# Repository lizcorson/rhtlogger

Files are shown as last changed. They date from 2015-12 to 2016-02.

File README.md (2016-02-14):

# rhtlogger
A temperature/relative humidity Arduino data logger. A sensor detects the current temperature and relative humidity. An LCD display updates every 3 seconds, and the values are logged to file every 30 seconds.

## Status

I soldered everything on to the proto shield, but I couldn't get the system to work reliably after that. I decided to completely redo everything using a Pro Mini because the stacking shields were annoying me. All of the new parts are still compatible with the same code.

## Parts Used

- Pro Mini Clone (5V) http://www.ebay.com/itm/231348215568 -- I especially like this new model because the A4/A5 I2C pins are in a much more convenient location
- Micro SD Card SPI module http://www.ebay.com/itm/Micro-SD-and-Memory-Card-Breakout-Shield-Module-via-SPI-For-Arduino-Regulated-/131426645939 - one that says Catalex on the back and has a voltage regulator
- DS3231 RTC http://www.ebay.com/itm/191782504379
- Clone of Sparkfun RHT Board HTU21D http://www.ebay.com/itm/310951642577?_trksid=p2057872.m2749.l2649&ssPageName=STRK%3AMEBIDX%3AIT (original: https://www.sparkfun.com/products/12064)
- 5V to 3.3V stepdown module http://www.ebay.com/itm/111896908030 (for the sensor, which is 3.3V)
- Frentaly i2c LCD http://www.ebay.com/itm/IIC-I2C-TWI-1602-Serial-Blue-Backlight-LCD-Display-For-Arduino-/221935534466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
- Momentary button https://www.sparkfun.com/products/11993
- 10k Ω resistor

Removed:
- SainSmart Uno http://smile.amazon.com/dp/B00E5WJSHK
- Arrela Data Logger Shield http://smile.amazon.com/dp/B00KHYHKT8 (I see this is no longer available - http://smile.amazon.com/dp/B00M1M8N90/ is probably a comparable replacement)
- tiny breadboard and/or protoshield with tiny breadboard http://www.ebay.com/itm/221739124245
- DHT22 sensor https://www.sparkfun.com/products/10167

## Libraries Used

- New LiquidCrystal library https://bitbucket.org/fmalpartida/new-liquidcrystal/downloads
- RTClib https://github.com/adafruit/RTClib
- HTU21D https://github.com/sparkfun/HTU21D_Breakout/tree/V_H1.2_L1.1.0/Libraries/Arduino

## Sample Data

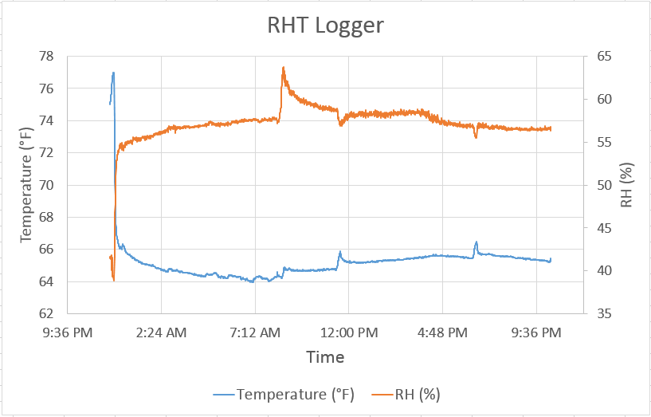
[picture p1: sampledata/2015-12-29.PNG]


## Photos

New breadboard prototype with the Pro Mini.

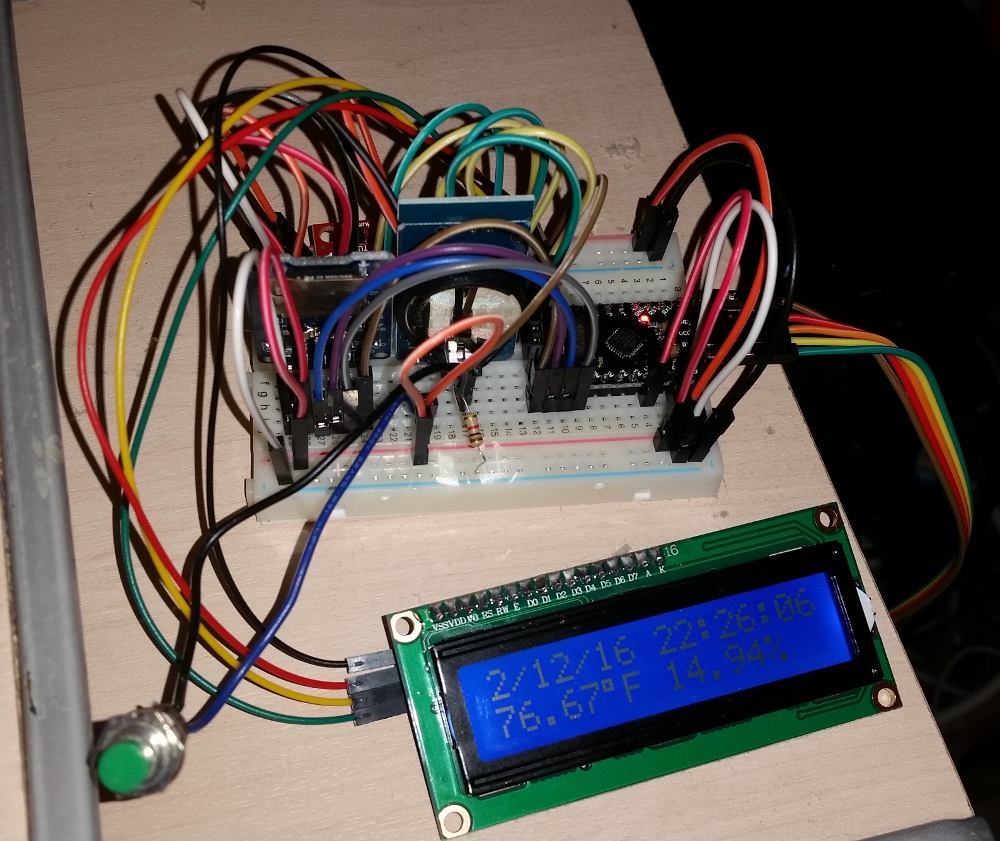
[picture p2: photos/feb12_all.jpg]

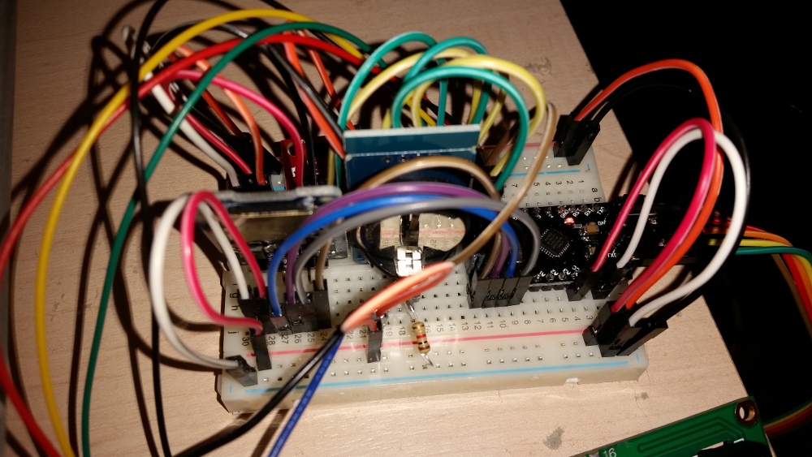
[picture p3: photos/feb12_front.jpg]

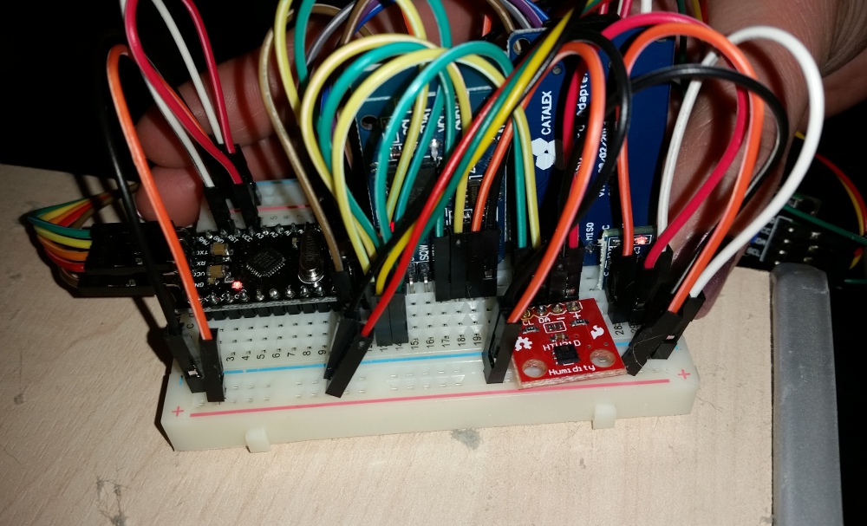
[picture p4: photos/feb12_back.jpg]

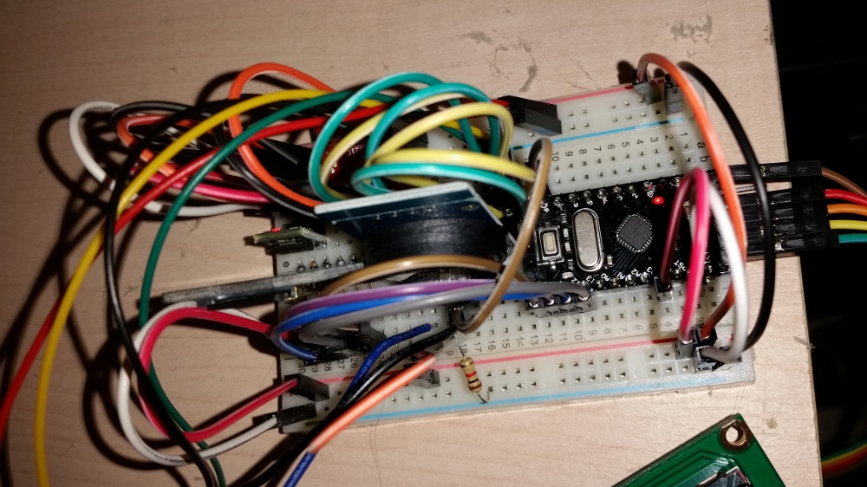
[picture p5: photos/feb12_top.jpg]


Proto-shield setup, which failed. 

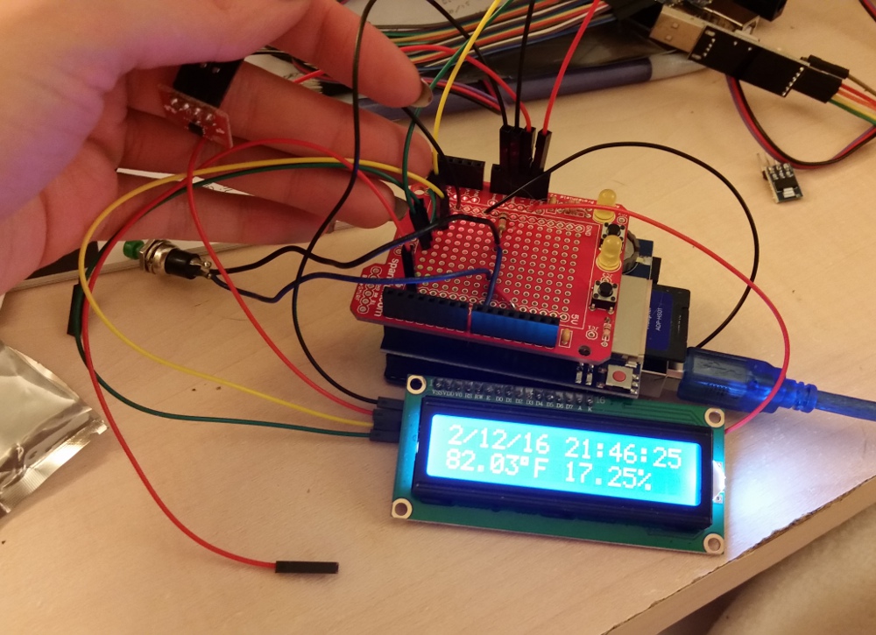
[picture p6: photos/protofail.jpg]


Original prototype with both DHT22 and HTU21D.

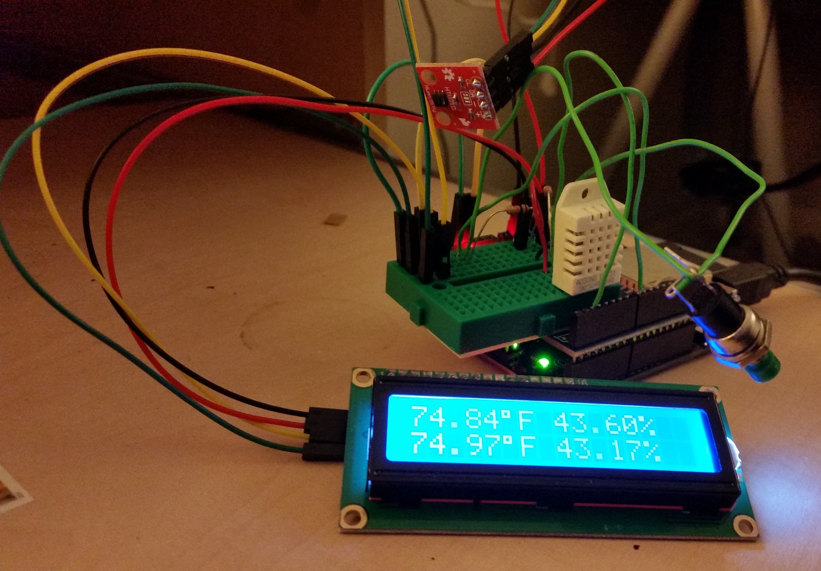
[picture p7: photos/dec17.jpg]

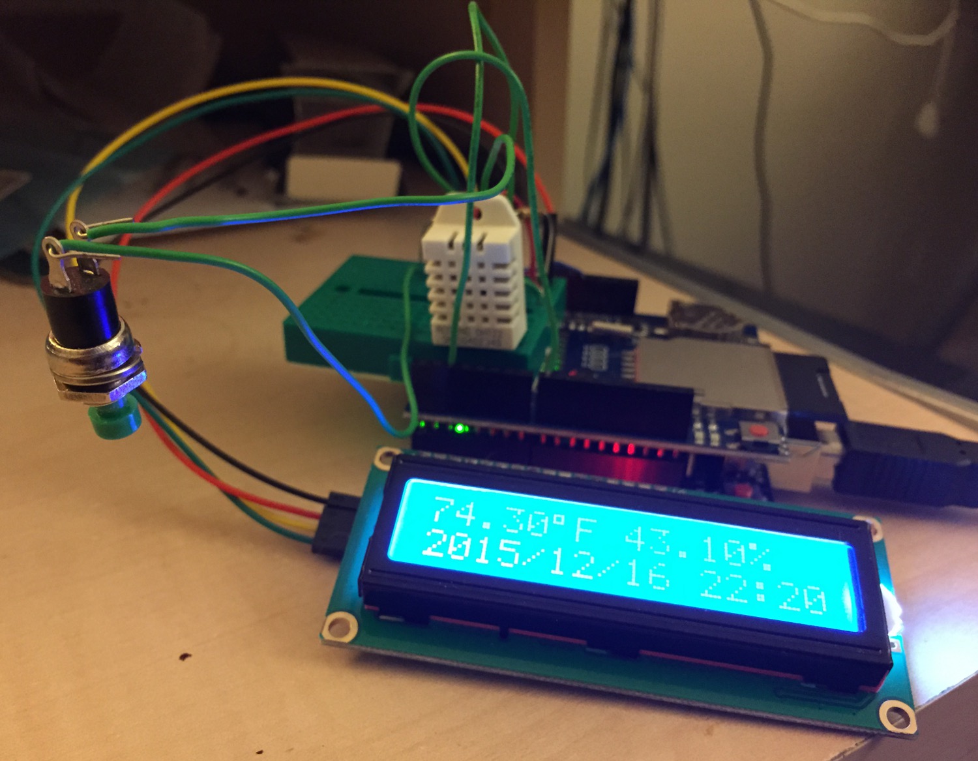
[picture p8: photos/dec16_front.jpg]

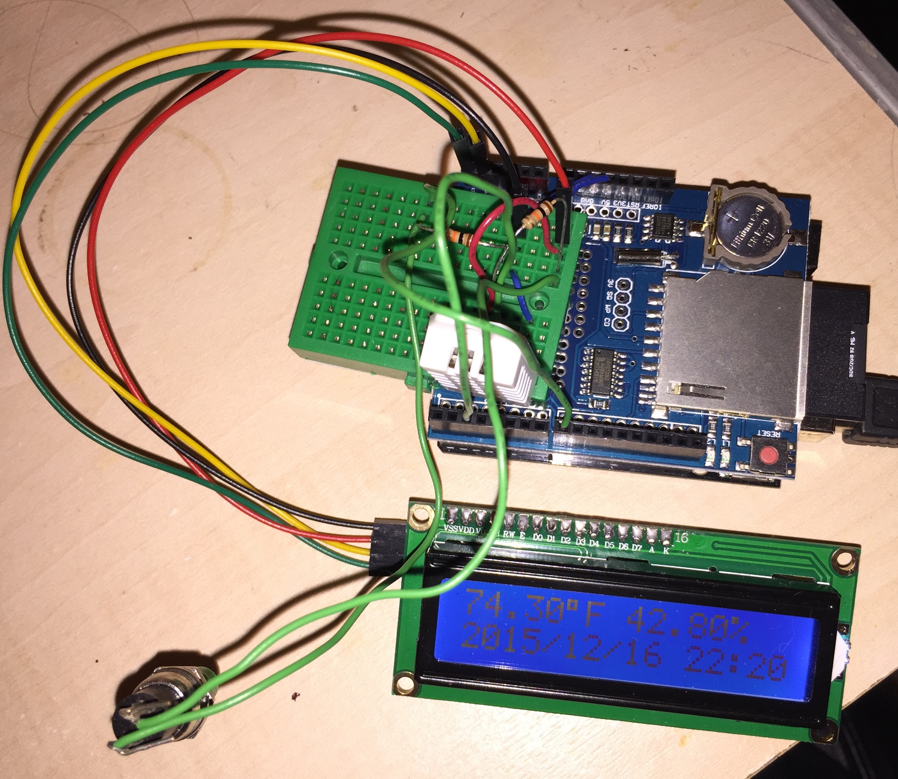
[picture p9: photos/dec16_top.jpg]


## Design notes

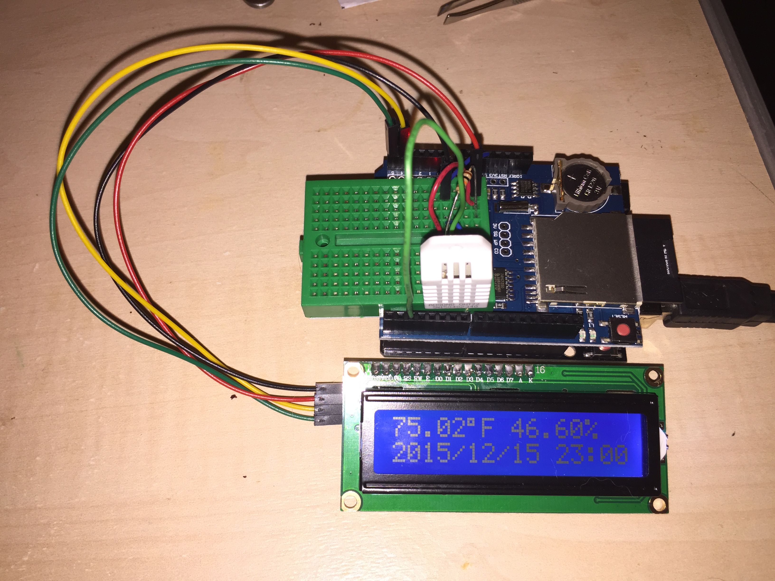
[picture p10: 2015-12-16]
photos/dec15.jpg

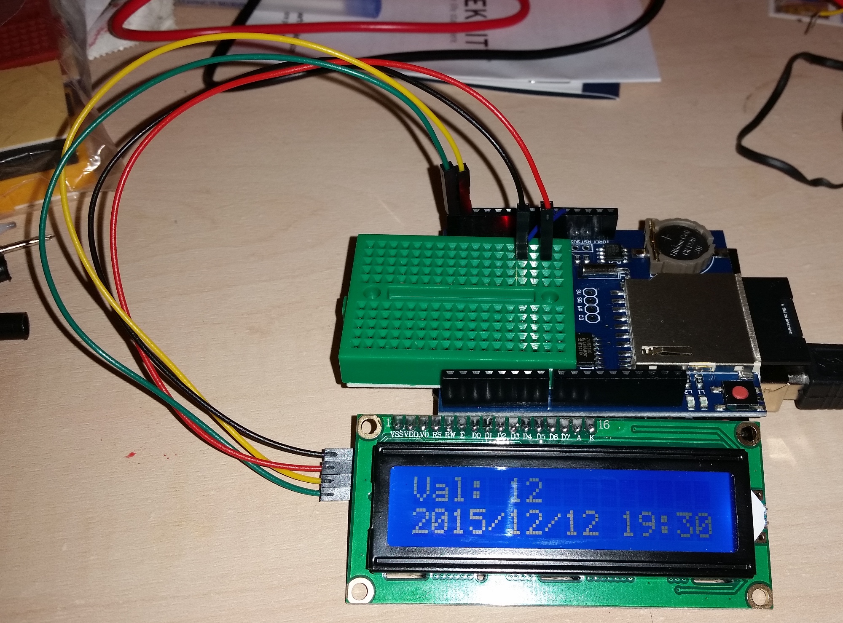
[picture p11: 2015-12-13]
photos/dec12.jpg

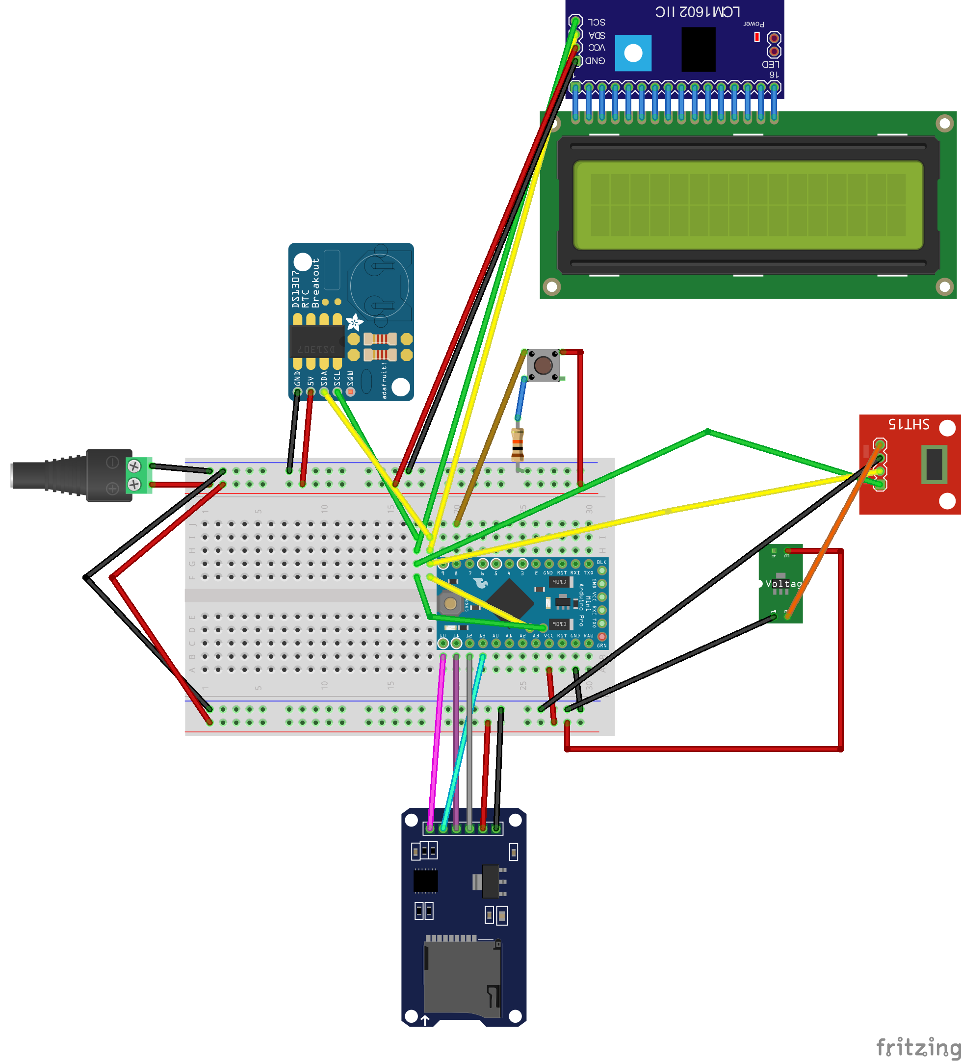
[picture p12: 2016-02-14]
circuitdiagram/rhtlogger_promini.png

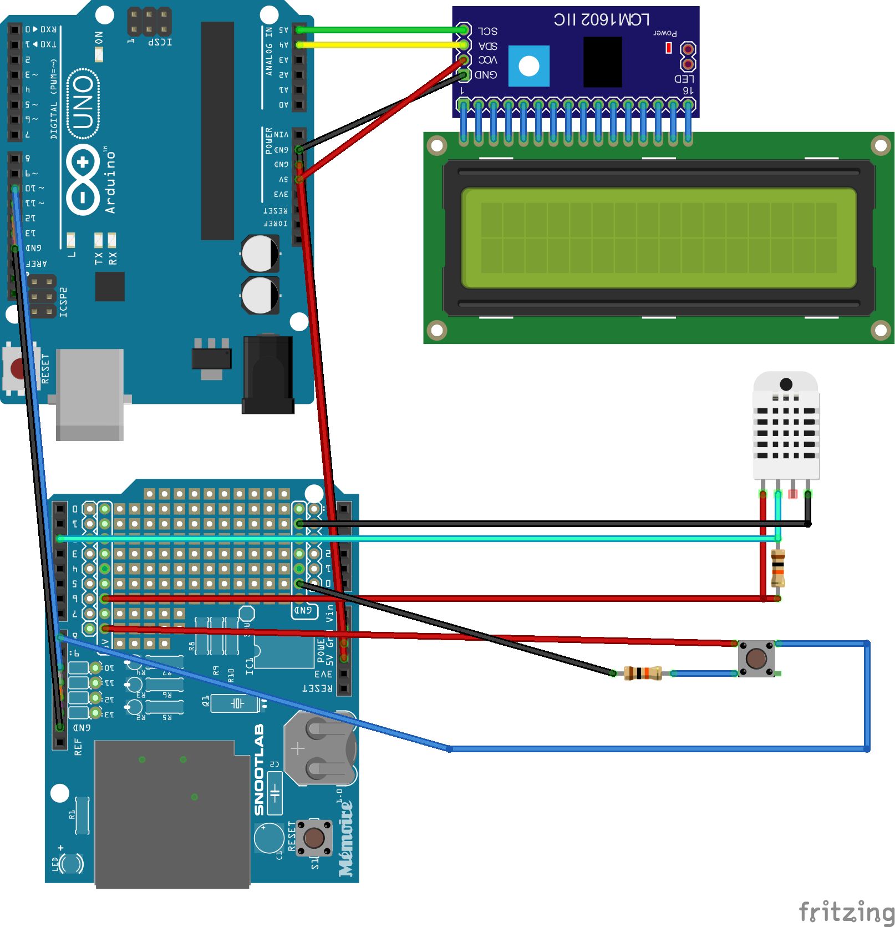
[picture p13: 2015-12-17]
circuitdiagram/rhtlogger_button.png

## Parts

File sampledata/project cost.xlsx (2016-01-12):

Item | Cost
Frentaly i2c LCD | 5.98
10k ohm resistor | 0.1
Momentary button | 0.95
HTU21D | 5.73
TOTAL | 12.76

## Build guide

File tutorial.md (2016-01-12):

# Tutorial
Here's how to put together your own version of my project. 

## Parts Used

- SainSmart Arduino Uno http://smile.amazon.com/dp/B00E5WJSHK
- Arrela Data Logger Shield http://smile.amazon.com/dp/B00KHYHKT8 (I see this is no longer available - http://smile.amazon.com/dp/B00M1M8N90/ is probably a comparable replacement)
- Clone of Sparkfun RHT Board HTU21D http://www.ebay.com/itm/310951642577?_trksid=p2057872.m2749.l2649&ssPageName=STRK%3AMEBIDX%3AIT (original: https://www.sparkfun.com/products/12064)
- Frentaly i2c LCD http://www.ebay.com/itm/IIC-I2C-TWI-1602-Serial-Blue-Backlight-LCD-Display-For-Arduino-/221935534466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
- Momentary button https://www.sparkfun.com/products/11993
- 10k Ω resistor
- tiny breadboard and/or protoshield with tiny breadboard http://www.ebay.com/itm/221739124245

## Assembly

Follow the circuit diagram. It's a mess, so I will explain here as well.

FIRST OF ALL, make sure everything is disconnected from power whenever you're wiring stuff!

Place the data logging shield on top of the Arduino. Optionally, put the protoshield and tiny breadboard on top of that, or just put your tiny breadboard on top of the data logging shield. I recommend putting everything together on the breadboard first and then soldering it to the protoshield once you're sure everything works.

Connect the A4 and A5 pins to the breadboard. I've used green for A5/SCL and yellow for A4/SDA. Connect the SDA and SCL lines to both the LCD and the HTU21D. You'll note that the fritzing diagram uses the part SHT15, because that's the closest I could find. I re-labelled the pins to be in the same order as the HTU21D.

Next, power. Connect 3.3V directly to VCC for the HTU21D. Everything else uses 5V. Connect 5V to the breadboard. Connect 5V to the LCD and one end of the button.

Ground: connect ground to the LCD and the HTU21D.

Button: the other end of the button is connected to a rail on the breadboard. Wire one spot on the rail to pin 8, and in another put the 10k pullup resistor. Connect the other end of the resistor to the ground rail.

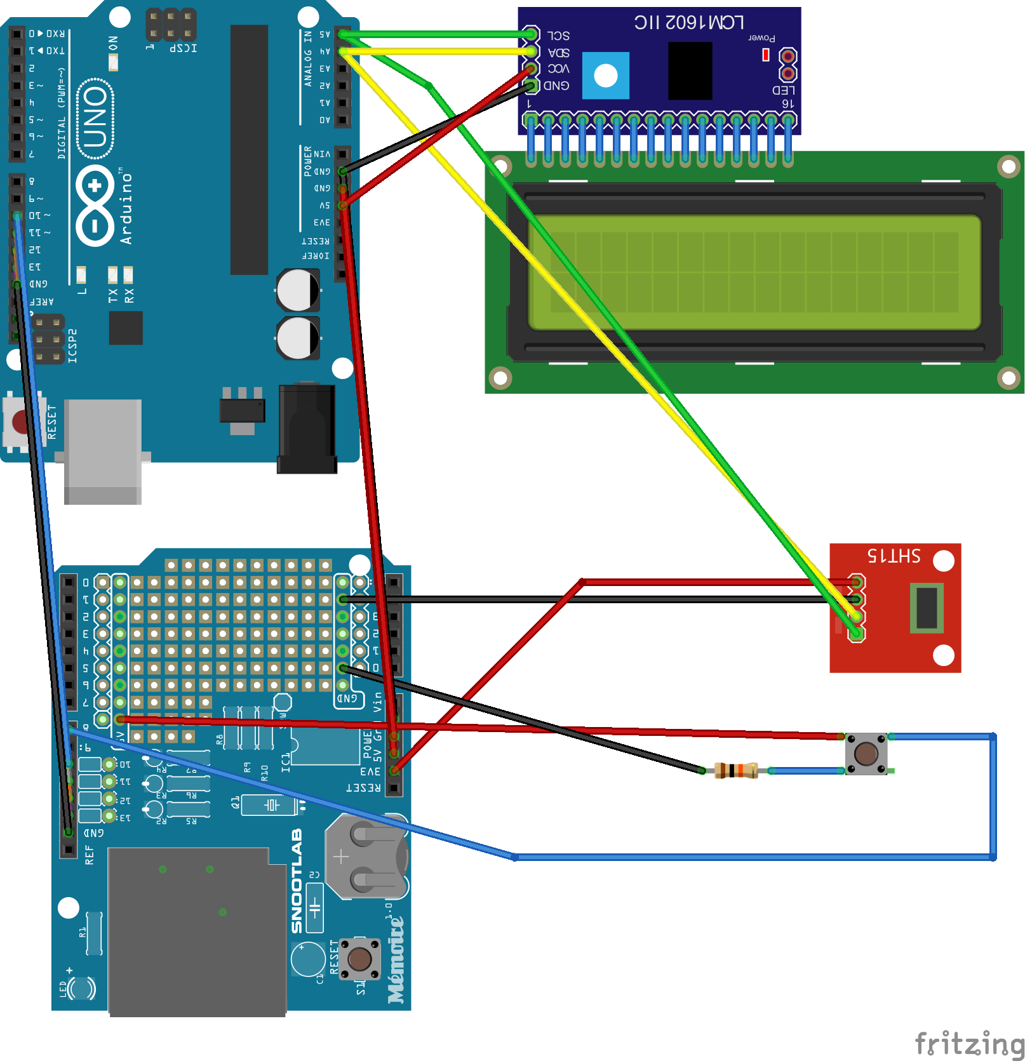
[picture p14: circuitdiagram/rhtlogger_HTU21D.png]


## Code

Download all the code in this repository. You'll want to use **rhtlogger2** as the main sketch. All the libraries required are in the library folder.

First, run the **i2cscanner** sketch to determine the address of your LCD. It will be either 0x27 or 0x3F.

Next, run the **rtclcdtest** sketch. Be sure to set the right i2c address for your LCD. This will set the clock on the RTC, and the time will display on the LCD. Mine tends to gain a few minutes per week, and you can also run this sketch to re-sync the time. If you're having problems with the LCD, this site has some variations on the LCD code: http://arduino-info.wikispaces.com/LCD-Blue-I2C#v1

Now your clock is set and your LCD is working, so you can proceed to upload the main sketch, **rhtlogger2**. Again, be sure to update the i2c address for the LCD.

Let it run for a few minutes, then pull the SD card to ensure it's writing to file. If it is, you're all set! If not, maybe your board uses a different chip select pin. Try the SD card library example sketches to try to get your SD card working.

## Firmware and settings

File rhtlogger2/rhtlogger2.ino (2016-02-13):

#include <Wire.h>
#include "RTClib.h"
#include <LiquidCrystal_I2C.h>//this is the special I2C LCD display library that came with the display
#include <SPI.h>
#include <SD.h>      //this includes the SD card libary that comes with the Arduino
#include "SparkFunHTU21D.h"

#define chipSelect 10//we are using pin#10 as chip select pin for the SD card
#define buttonPin 8 
long lastFileWrite = 0;
long lastDisplayWrite = 0;
int powerStatus = 1;
long lastDebounceTime = 0;
long debounceDelay = 300;

// set the LCD address to 0x27 or 0x3F for a 16 chars 2 line display
// Set the pins on the I2C chip used for LCD connections:
//                    addr, en,rw,rs,d4,d5,d6,d7,bl,blpol
LiquidCrystal_I2C lcd(0x27, 2, 1, 0, 4, 5, 6, 7, 3, POSITIVE);  // Set the LCD I2C address
HTU21D myHumidity;
RTC_DS1307 RTC;
 
void setup () {
  Serial.begin(38400);
  Wire.begin();
  RTC.begin();
  myHumidity.begin();

  pinMode(buttonPin, INPUT);

 // RTC Adjustment. Only needed when setting time after battery is removed.
  /*if (! RTC.isrunning()) {
    Serial.println("RTC is NOT running!");
    // following line sets the RTC to the date & time this sketch was compiled
    RTC.adjust(DateTime(__DATE__, __TIME__));
  }*/
  //uncomment to adjust time regardless of whether it's already set
  //RTC.adjust(DateTime(__DATE__, __TIME__));
  lcd.begin(16,2);   // initialize the lcd for 16 chars 2 lines, turn on backlight
  lcd.backlight();

  //set up SD card
  Serial.print("Initializing SD card..."); 
  if (!SD.begin(chipSelect)) { // see if the card is present and can be initialized:
    Serial.println("Card failed, or not present");
    lcd.setCursor(0,0);
    lcd.print("SD Card Fail"); //notify of SD card fail
    delay(3000); // wait 3 sec so user sees message
    return;//exit the setup function. This quits the setup() and the program counter jumps to the loop().
  }
  Serial.println("card initialized.");//otherwise, tell us that the card was successfully initialized. 
}
 
void loop () {
  DateTime now = RTC.now();

  //check for button press
  int buttonRead = digitalRead(buttonPin);
  
  if (buttonRead && (unsigned long)(millis() - lastDebounceTime) > debounceDelay) { // if button is pressed AND it's been at least 200 ms since the last press
    //flip power status
    if (powerStatus == 1) {
      powerStatus = 0; 
      Serial.println("Powering down.");
      Serial.println(buttonRead);
      lcd.noBacklight();//this turns the backlight off
      lcd.clear();
    }
    else {
      powerStatus = 1;
      Serial.println("Powering up.");
      Serial.println(buttonRead);
      lcd.backlight(); // turn backlight on    
    }
    lastDebounceTime = millis(); // set new button-last-pressed time
  }

  //only write to file every 30 sec
  if ((unsigned long)(millis() - lastFileWrite) >= 30000) {
    float temperature = myHumidity.readTemperature()*1.8+32; //convert to F
    float rh = myHumidity.readHumidity();
    //write to SD time and value
    String dataString = getDigitalTime(now) + String(",") + String(temperature) + String(",") + String(rh); //concatenate (add together) a string consisting of the time and the sensor reading at that time
    String filename = getFileName(now); // "rhtlog.txt"
    File dataFile = SD.open(filename, FILE_WRITE);//open a file named datalog.txt. FILE_WRITE mode specifies to append the string at the end of the file
                         //file names must adhere to the "8.3 format"(max 8 char in the name, and a 3 char extension)
                         //if there is no file of that name on the SD card, this .open method will create a new file.
                         //This line actually instantiates an File object named "datafile"      
   
    if (dataFile) {       // if the file is available, write to it ('datafile' is returned 1 if SD.open was successful.
      dataFile.println(dataString);//print the concatenated data string and finish the line with a carriage return (println adds the CR automatically after printing the string)
      dataFile.close();   //close the file. IT is a good idea to always open/close a file before and after writing to it. That way, if someone removes the card the file is most
                        //likely o.k. and can be read with the computer.
      lastFileWrite = millis();
      Serial.println(dataString);// print the string also to the serial port, so we can see what is going on.
    }  
    else { // if SD.open is not successful it returns a 0, i.e. the else{} is executed if the file could not be opened/created successfully.
      Serial.println("error opening timelog.txt");//in that case print an error message
      lcd.setCursor(0,1);
      lcd.print("File Error"); 
      lastFileWrite = millis(); // still set this marker bc I don't want it to constantly try to write to file if there's an error
    }
  }

  //update the display every 3 seconds if the LCD is on
  if ((unsigned long)(millis() - lastDisplayWrite) >= 3000 && powerStatus) {
    float dispT = myHumidity.readTemperature()*1.8+32; //convert to F
    float dispRH = myHumidity.readHumidity();
    char deg = (char)223;
    String printString = String(dispT) + String(deg) + String("F ") + String(dispRH)  + String("%  ");
    String serialString = getLCDDateTime(now) + " " + printString;
    
    Serial.println(serialString);
    lcd.setCursor(0,0);
    String printTime = getLCDDateTime(now) + "  "; //make sure it takes up the whole line so no stray characters after date rolls over ie from 30th to 1st
    lcd.print(printTime);
    lcd.setCursor(0,1);
    lcd.print(printString); 
    lastDisplayWrite = millis();
  }
}

String getLCDDateTime (DateTime now) {
  String hourstring = "";
  String minstring = "";
  String secstring = "";  
  
  String yearstring = String(now.year()-2000);
  
  //add zeros to front of 1 character time components  
  if (now.hour() < 10) {
    hourstring = String(0) + String(now.hour());
  }
  else {
    hourstring = String(now.hour());
  }
  if (now.minute() < 10) {
    minstring = String(0) + String(now.minute());
  }
  else {
    minstring = String(now.minute());
  }
  if (now.second() < 10) {
    secstring = String(0) + String(now.second());
  }
  else {
    secstring = String(now.second());
  }
  String result = String(now.month()) + '/' + String(now.day()) + '/' + String(yearstring) + ' ' + hourstring + ':' + minstring + ':' + secstring;  
  return result;
}

String getDigitalTime (DateTime now) {
  String hourstring = "";
  String minstring = "";
  String secstring = "";  
  
  //add zeros to front of 1 character time components  
  if (now.hour() < 10) {
    hourstring = String(0) + String(now.hour());
  }
  else {
    hourstring = String(now.hour());
  }
  if (now.minute() < 10) {
    minstring = String(0) + String(now.minute());
  }
  else {
    minstring = String(now.minute());
  }
  if (now.second() < 10) {
    secstring = String(0) + String(now.second());
  }
  else {
    secstring = String(now.second());
  }
  String result = String(now.year()) + '/' + String(now.month()) + '/' + String(now.day()) + ' ' + hourstring + ':' + minstring + ':' + secstring;  
  return result;
}

String getFileName (DateTime now) {
  String monthstring = "";
  if (now.month() < 10) {
    monthstring = String(0) + String(now.month());
  }
  else {
    monthstring = String(now.month());
  }
  
  String daystring = "";
  if (now.day() < 10) {
    daystring = String(0) + String(now.day());
  }
  else {
    daystring = String(now.day());
  }
  
  String filename = String(now.year()) + monthstring + daystring + ".txt";
  return filename;
}

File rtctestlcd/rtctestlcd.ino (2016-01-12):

// Date and time functions using a DS1307 RTC connected via I2C and Wire lib
 
#include <Wire.h>
#include "RTClib.h"
#include <LiquidCrystal_I2C.h>//this is the special I2C LCD display library that came with the display

 
RTC_DS1307 RTC;
// set the LCD address to 0x27 or 0x3F for a 16 chars 2 line display
// Set the pins on the I2C chip used for LCD connections:
//                    addr, en,rw,rs,d4,d5,d6,d7,bl,blpol
LiquidCrystal_I2C lcd(0x27, 2, 1, 0, 4, 5, 6, 7, 3, POSITIVE);  // Set the LCD I2C address

 
void setup () {
//    Serial.begin(57600);
    Serial.begin(38400);
    Wire.begin();
    RTC.begin();
 
  if (! RTC.isrunning()) {
    Serial.println("RTC is NOT running!");
    // following line sets the RTC to the date & time this sketch was compiled
    RTC.adjust(DateTime(__DATE__, __TIME__));
  }
  //uncomment to adjust time regardless of whether it's set
  RTC.adjust(DateTime(__DATE__, __TIME__));
  
  lcd.begin(16,2);   // initialize the lcd for 16 chars 2 lines, turn on backlight
  lcd.backlight();
 
}
 
void loop () {
    DateTime now = RTC.now();
 
    Serial.print(now.year(), DEC);
    Serial.print('/');
    Serial.print(now.month(), DEC);
    Serial.print('/');
    Serial.print(now.day(), DEC);
    Serial.print(' ');
    Serial.print(now.hour(), DEC);
    Serial.print(':');
    Serial.print(now.minute(), DEC);
    Serial.print(':');
    Serial.print(now.second(), DEC);
    Serial.println();
 
    Serial.print(" since 1970 = ");
    Serial.print(now.unixtime());
    Serial.print("s = ");
    Serial.print(now.unixtime() / 86400L);
    Serial.println("d");
 
    // calculate a date which is 7 days and 30 seconds into the future
    DateTime future (now.unixtime() + 7 * 86400L + 30);
 
    Serial.print(" now + 7d + 30s: ");
    Serial.print(future.year(), DEC);
    Serial.print('/');
    Serial.print(future.month(), DEC);
    Serial.print('/');
    Serial.print(future.day(), DEC);
    Serial.print(' ');
    Serial.print(future.hour(), DEC);
    Serial.print(':');
    Serial.print(future.minute(), DEC);
    Serial.print(':');
    Serial.print(future.second(), DEC);
    Serial.println();
 
    Serial.println();
    delay(1000);
    
    //Serial.println(getDigitalTime(now));
    lcd.setCursor(0,0);
    lcd.print(getDigitalDate(now));
    lcd.setCursor(0,1);
    lcd.print(getDigitalTimeOnly(now));
}

String getDigitalDate (DateTime now) {
    String result = String(now.year()) + '/' + now.month() + '/' + now.day();    
    return result;
}
String getDigitalTimeOnly (DateTime now) {
  String hourstring = "";
  String minstring = "";
  String secstring = "";
  String ampm = "";  
  
  //add zeros to front of 1 character time components  
  if (now.hour() < 10) {
    hourstring = String(0) + String(now.hour());
    ampm = "AM";
  }
  else if (now.hour() > 12) {
    int adjHour = now.hour() - 12;
    if (adjHour < 10) {
      hourstring = String(0) + String(adjHour);
    }
    else {
      hourstring = String(adjHour);  
    }
    ampm = "PM";
  }
  if (now.minute() < 10) {
    minstring = String(0) + String(now.minute());
  }
  else {
    minstring = String(now.minute());
  }
  if (now.second() < 10) {
    secstring = String(0) + String(now.second());
  }
  else {
    secstring = String(now.second());
  }

  
  String result = hourstring + ':' + minstring + ':' + secstring + ' ' + ampm;  
  return result;
}

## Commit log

2015-12-08 Dec 7 Update
    I've got the data logger shield working. It's recording a random value
    and the timestamp to a text file. Next step will be to add the sensor
    itself and possibly an LCD screen.
2015-12-13 Dec 12 updates
    Got the LCD working.
    [rhtlogger.fzz]
2015-12-16 DHT22
    This version works with the DHT22 sensor.
    [rhtlogger.fzz]
2015-12-17 Dec 16 update
    Added a button to turn the LCD on and off. Changed file write frequency
    to once per minute. The display still updates every 5 seconds but the
    program only writes to file once a minute.
    [rhtlogger.fzz]
2015-12-18 HTU21D
    Added HTU21D sensor.
2015-12-29 Starting Rebuild
    Due to strange errors, I am rebuilding the code to only use the HTU21D.
    [rhtlogger2.ino]
2015-12-29 Rebuilt
    Rebuilt without TimerOne which was mysteriously breaking my code.
2015-12-30 Sample Data
    After a day of testing everything seems to be working.
    [2015-12-29.xlsx]
2015-12-30 axis labels
    Fixing axis labels
    [2015-12-29.xlsx]
2015-12-31 Case
    Added plans for case to be laser cut.
2015-12-31 code cleanup
    Purging all the TimerOne comments that I don't need anymore.
2016-01-12 Jan 11
    Filename is now YYYYMMDD.txt to avoid really long files. Updated circuit
    diagram to use HTU21D sensor. Added tutorial and some support code.
    [project cost.xlsx, rhtlogger.fzz]
2016-02-13 Pro Mini version
    Completely redone using Pro Mini and individual modules instead of an
    Uno with shields.
    [rhtlogger_promini.fzz]
2016-02-14 Circuit Diagram Update
    Added missing voltage regulator to send 3.3V to sensor.
    [rhtlogger_promini.fzz]
